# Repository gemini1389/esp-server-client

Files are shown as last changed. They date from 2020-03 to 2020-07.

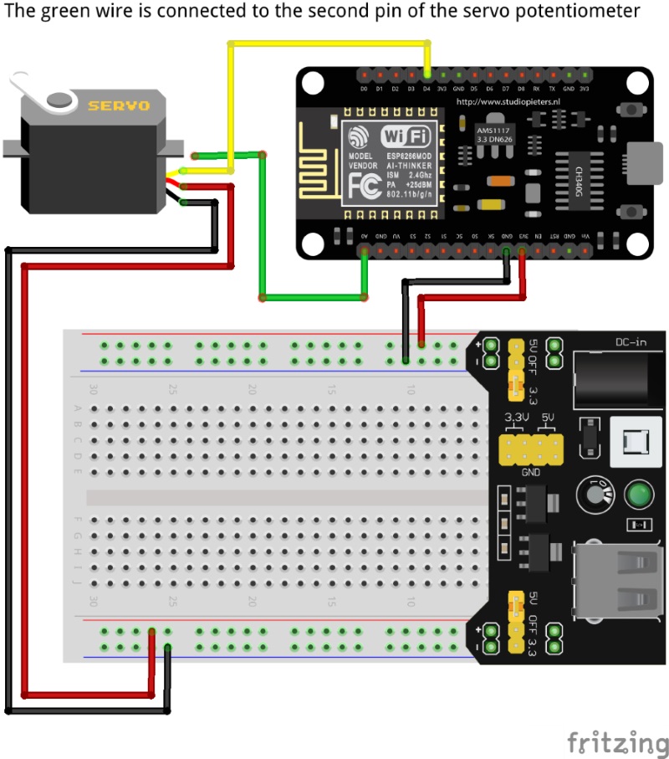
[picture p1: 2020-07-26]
main/main.jpg

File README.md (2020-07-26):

## Web Server using ESP8622 with servo and client with OLED
The project consists of two parts:
- main ([scheme](main/main.jpg))
- client ([scheme](client/client.jpg))

**main** - the web server with servo. Has a web interface for browsers that allows you to control the servo. There is also an API-like endpoint that returns the servo status in JSON format.

**client** - a web client that connects to main via Wi-Fi, receives information about the status of the servo and displays it on the OLED display.

A fourth wire was connected to the servo. It is soldered
  to the second output of the potentiometer inside the servo and connected to A0 on the board. The values are not very accurate, but they are enough to understand whether the servo has turned to the desired angle or not.

This sketch is set to rotate the servo in the range of 45-105 degrees. Equivalent values were also found for analog polling of the servo.

### Interfaces

Web interface: http://192.168.1.13/

API endpoint: http://192.168.1.13/status

### Default settings
**Wi-Fi:**
```
const char* ssid     = "AGS-WiFi";
const char* password = "qwepoi123654789";
```

**Network**
```
IPAddress local_IP(192, 168, 1, 13);
IPAddress gateway(192, 168, 1, 13);
IPAddress subnet(255, 255, 255, 0);
```

**Servo**
```
#define servoDegreeMin  45  // 0
#define servoDegreeMax  105 // 170

#define servoAnalogMin  348 // 221
#define servoAnalogMax  493 // 665
```

### Libraries for Arduino IDE:
- [ESP8266 and ESP32 OLED driver for SSD1306 displays](https://github.com/ThingPulse/esp8266-oled-ssd1306)
- [Arduino_JSON](http://github.com/arduino-libraries/Arduino_JSON)
- [Servo](http://www.arduino.cc/en/Reference/Servo)

### Hardware for project:
- Lolin NodeMCU v3 (x2)
- Sparkfun S05NF (micro)
- 0.96" OLED Display Module 128X64 I2C
- Dupont wires
- Breadboard
- Micro USB Cable
- MB102 Breadboard Power Supply
- DC 9V 1A Power Supply Adapter 5.5x2.1mm

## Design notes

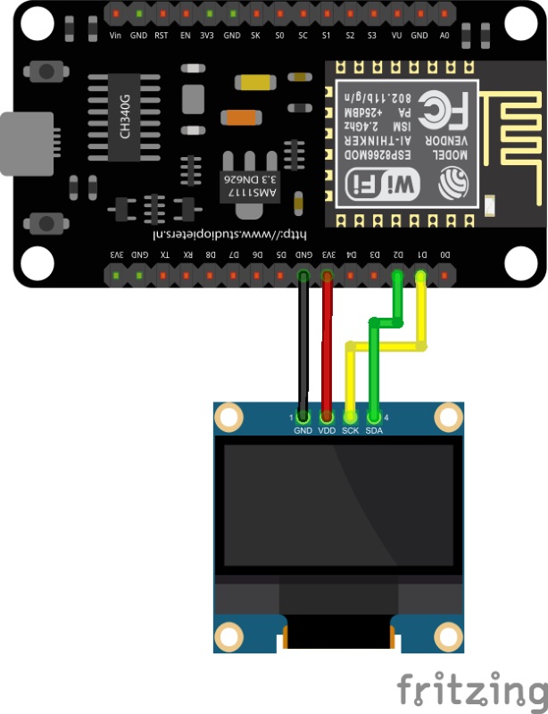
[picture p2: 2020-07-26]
client/client.jpg

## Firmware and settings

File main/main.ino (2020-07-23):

#include <Servo.h>
#include <ESP8266WiFi.h>
#include <ESP8266WebServer.h>
#include <Arduino_JSON.h>

// Print messages to Serial
#define DEBUG_MODE true

// GPIO the servo is attached to
#define pinServo        D4
#define pinServoAnalog  A0

// Config for servo
#define servoDelay        8
#define servoDiagDelay    30
#define servoMinUs        720  // 0
#define servoMaxUs        2400 // 180
#define servoMaxAttempts  3

// Min and max degree for rotation servo
#define servoDegreeMin  45  // 0
#define servoDegreeMax  105 // 170

// Min and max analog values
#define servoAnalogMin  348 // 221
#define servoAnalogMax  493 // 665

// Possible difference between values
#define servoAnalogDegreesDiff  5
#define servoAnalogAnalogDiff   50

// Credentials for Wi-Fi
const char* ssid     = "AGS-WiFi";
const char* password = "qwepoi123654789";

// Config for network
IPAddress local_IP(192, 168, 1, 13);
IPAddress gateway(192, 168, 1, 13);
IPAddress subnet(255, 255, 255, 0);

int newDegree = servoDegreeMin;
int analogDegree;
unsigned long timer;

Servo servo;
ESP8266WebServer server(80);

void setup() {
  delay(2000);

  if (DEBUG_MODE) {
    Serial.begin(115200);
  }
  println("[INIT] Debug mode is enabled");
  println("[INIT] Starting...");

  initWiFi();
  println("--------------");
  initServer();
  println("--------------");
  initServo();
  println("--------------");
  servoDiagnostics();

  println("[INIT] Initialization is complete");
}

void loop() {
  server.handleClient();
}

// Rotate servo
bool writeServo(int degree, bool isDiagnostics = false) {
  int start = getAnalogDegree();
  int end = degree;
  int position;

  if (start > end) {
    for (position = start; position >= end; position--)
    {
      servo.write(position);
      delay(isDiagnostics ? servoDiagDelay : servoDelay);
    }
  } else {
    for (position = start; position <= end; position++)
    {
      servo.write(position);
      delay(isDiagnostics ? servoDiagDelay : servoDelay);
    }
  }

  delay(100);

  return isServoRotated(degree);
}

// Main page
void handleRoot() {
  String ptr = "<!DOCTYPE html> <html>\n";
  ptr += "<head>\n";
  ptr += "<meta name=\"viewport\" content=\"width=device-width, initial-scale=1\">\n";
  ptr += "<link rel=\"icon\" href=\"data:,\">\n";

  ptr += "<style>body { text-align: center; font-family: \"Trebuchet MS\", Arial; margin-left:auto; margin-right:auto;}\n";
  ptr += ".slider { width: 300px; }</style>\n";

  // Web Page
  ptr += "</head><body><h1>ESP8266 with Servo</h1>\n";
  ptr += "<p>Position: <span id=\"servoPos\"></span></p>\n";
  ptr += "<input type=\"range\" min=\"" + String(servoDegreeMin) + "\" max=\"" + String(servoDegreeMax) + "\" class=\"slider\" id=\"servoSlider\" value=\"" + String(newDegree) + "\"/>";

  ptr += "<script>\n";
  ptr += "  var slider = document.getElementById(\"servoSlider\");\n";
  ptr += "  var servoP = document.getElementById(\"servoPos\");\n";
  ptr += "  servoP.innerHTML = slider.value;\n";
  ptr += "  slider.oninput = function() {\n";
  ptr += "    slider.value = this.value;\n";
  ptr += "    servoP.innerHTML = this.value;\n";
  ptr += "  }\n";
  ptr += "function servo() {\n";
  ptr += "  var xmlHttp = new XMLHttpRequest();\n";
  ptr += "  xmlHttp.open('GET', '/?value=' + this.value, false);\n";
  ptr += "  xmlHttp.send(null);\n";
  ptr += "  return xmlHttp.responseText;\n";
  ptr += "}\n";
  ptr += "document.getElementById('servoSlider').addEventListener('change', servo, false);\n";
  ptr += "</script>\n";

  ptr += "</body></html>";

  //GET /?value=180 HTTP/1.1
  if (server.arg("value") != "") {
    newDegree = myConstrain(server.arg("value").toInt(), servoDegreeMin, servoDegreeMax);

    bool rotated = false;
    byte attempts = 1;
    while (!rotated && attempts <= servoMaxAttempts) {
      rotated = writeServo(newDegree);
      if (!rotated) {
        println("[FAIL] Servo rotation error! Attempt: " + String(attempts) + "/" + String(servoMaxAttempts));
        attempts++;
        delay(100);
      }
    }
  }

  server.send(200, "text/html", ptr);
}

// Endpoint for getting status
void handleStatus() {
  JSONVar statusObj;

  statusObj["servoDegreeCurrent"] = newDegree;
  statusObj["servoDegreeMin"] = servoDegreeMin;
  statusObj["servoDegreeMax"] = servoDegreeMax;

  server.send(200, "application/json", JSON.stringify(statusObj));
}

// My constrain function
int myConstrain(int value, int minVal, int maxVal) {
  if (value < minVal) {
    value = minVal;
  }

  if (value > maxVal) {
    value = maxVal;
  }
  return value;
}

// Returns analog degree for servo
int getAnalogDegree() {
  int analogVal = analogRead(pinServoAnalog);
  analogVal = myConstrain(analogVal, servoAnalogMin, servoAnalogMax);
  analogDegree = map(analogVal, servoAnalogMin, servoAnalogMax, servoDegreeMin, servoDegreeMax);

  return analogDegree;
}

// It returns the status of whether the servo turned
bool isServoRotated(int degreeNeedle) {
  bool rotated = false;

  // Check by analog value
  int analogVal = analogRead(pinServoAnalog);
  int checkMinAnalog = servoAnalogMin - servoAnalogAnalogDiff;
  int checkMaxAnalog = servoAnalogMax + servoAnalogAnalogDiff;
  rotated = analogVal > checkMinAnalog && analogVal < checkMaxAnalog;

  print("[INFO] Analog: ");
  print(String(analogVal));
  println(" | Diff min: " + String(checkMinAnalog) + " | Diff max: " + String(checkMaxAnalog));

  // Check by digital value
  if (rotated) {
    int degreeAnalog = getAnalogDegree();
    int checkMin = degreeNeedle - servoAnalogDegreesDiff;
    int checkMax = degreeNeedle + servoAnalogDegreesDiff;
    rotated = degreeAnalog > checkMin && degreeAnalog < checkMax;

    print("[INFO] Digital: ");
    print(String(degreeAnalog) + "/" + String(degreeNeedle) + " (Analog/Digital)");
    println(" | Diff min: " + String(checkMin) + " | Diff max: " + String(checkMax));
  }

  println(rotated ? "[OK] Servo is rotated!" : "[FAIL] Servo is not rotated!");

  return rotated;
}

// Wi-Fi initialization
void initWiFi() {
  WiFi.softAPConfig(local_IP, gateway, subnet);
  while (WiFi.softAP(ssid, password) != true) {
    delay(750);
  }

  println("[INIT] AP SSID: " + String(ssid));
  println("[INIT] AP IP: " + WiFi.softAPIP().toString());
}

// Servo initialization
void initServo() {
  pinMode(pinServoAnalog, INPUT);

  servo.attach(
    pinServo,
    servoMinUs,
    servoMaxUs
  );

  if (servo.attached()) {
    println("[INIT] Servo attached");
  }

  writeServo(newDegree);
}

// Server initialization
void initServer() {
  server.on("/", handleRoot);
  server.on("/status", handleStatus);
  server.begin();

  println("[INIT] HTTP server started");
}

// Diagnostics for servo
void servoDiagnostics() {
  println("[INIT] Servo diagnostics: start");

  bool diagStatus = true;
  diagStatus = writeServo(servoDegreeMax, true);

  print(diagStatus ? "[OK]" : "[FAIL]");
  println(" Servo diagnostics #1 (to " + String(servoDegreeMax) + "°)");

  if (diagStatus) {
    diagStatus = writeServo(servoDegreeMin, true);
  }

  print(diagStatus ? "[OK]" : "[FAIL]");
  println(" Servo diagnostics #2 (to " + String(servoDegreeMin) + "°)");

  if (diagStatus) {
    diagStatus = writeServo(servoDegreeMax, true);
  }

  print(diagStatus ? "[OK]" : "[FAIL]");
  println(" Servo diagnostics #3 (to " + String(servoDegreeMax) + "°)");

  if (diagStatus) {
    diagStatus = writeServo(servoDegreeMin, true);
  }

  print(diagStatus ? "[OK]" : "[FAIL]");
  println(" Servo diagnostics #4 (to " + String(servoDegreeMin) + "°)");

  if (!diagStatus) {
    while (true) {
      if (millis() - timer >= 3000) {
        timer = millis();
        println("[FAIL] Servo diagnostics: Shit happens...");
      }
    }
  }

  println("[INIT] Servo diagnostics: success");
}

// Print message to Serial
void print(String message) {
  if (DEBUG_MODE) {
    Serial.print(message);
  }
}

// Print message to Serial
void println(String message) {
  if (DEBUG_MODE) {
    Serial.println(message);
  }
}

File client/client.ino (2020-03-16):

#include <ESP8266WiFi.h>
#include <ESP8266HTTPClient.h>
#include <WiFiClient.h>
#include <SSD1306Wire.h>
#include <Arduino_JSON.h>

// Print messages to Serial
#define DEBUG_MODE true

// GPIO the display is attached to
#define pinDisplaySDA D2
#define pinDisplaySCL D1

// Credentials for Wi-Fi
const char* ssid     = "AGS-WiFi";
const char* password = "qwepoi123654789";

// Endpoints
const char* endpointStatus = "http://192.168.1.13/status";

const long interval = 2 * 1000;
unsigned long previousMillis = 0;
bool doReconnect = false;

int servoDegreeCurrent;
int servoDegreeMin;
int servoDegreeMax;
int progress;

SSD1306Wire display(0x3c, pinDisplaySDA, pinDisplaySCL);

void setup() {
  delay(2000);

  if (DEBUG_MODE) {
    Serial.begin(74880);
  }
  println("Debug mode is enabled");
  println("Starting...");

  initDisplay();
  initWiFi();
}

void loop() {
  unsigned long currentMillis = millis();

  if (currentMillis - previousMillis >= interval) {
    if (WiFi.isConnected()) {
      processing();

      // save the last HTTP GET Request
      previousMillis = currentMillis;
    }
    else {
      doReconnect = true;
      println("WiFi Disconnected");
    }

    if (doReconnect) {
        WiFi.reconnect();
        connectionWiFi();
        doReconnect = false;
        println("WiFi Reconnected");
    }
  }
}

// Processing
void processing() {
  JSONVar payload = httpGETRequest(endpointStatus);

  if (payload.hasOwnProperty("servoDegreeCurrent")
      && payload.hasOwnProperty("servoDegreeMin")
      && payload.hasOwnProperty("servoDegreeMax"
  )) {
    servoDegreeCurrent = payload["servoDegreeCurrent"];
    servoDegreeMin = payload["servoDegreeMin"];
    servoDegreeMax = payload["servoDegreeMax"];
    progress = (servoDegreeCurrent - servoDegreeMin) * 100 / (servoDegreeMax - servoDegreeMin);

    println("Servo rotated: " + String(servoDegreeCurrent) + " | Progress: " + String(progress));
    println("Rotation min: " + String(servoDegreeMin) + " | Rotation max: " + String(servoDegreeMax));

    getDisplayHeader();
    display.setFont(ArialMT_Plain_16);
    display.drawString(54, 30, String(servoDegreeCurrent) + "°");
    display.drawProgressBar(0, 46, 127, 10, progress);
    display.display();
  }
}

// Send GET request
JSONVar httpGETRequest(const char* endpoint) {
  WiFiClient client;
  HTTPClient http;

  String data = "";
  if (http.begin(client, endpoint)) {
    int httpResponseCode = http.GET();
    println("Response code: " + String(httpResponseCode));

    if (httpResponseCode > 0) {
      data = http.getString();
    } else {
      doReconnect = true;
      println("Bad request");
    }
  }
  else {
    doReconnect = true;
    println("Unable to connect");
  }

  // Free resources
  http.end();

  JSONVar payload = JSON.parse(data);

  return payload;
}

// Get header for display
void getDisplayHeader() {
  display.setFont(ArialMT_Plain_10);
  display.clear();
  display.drawString(0, 0, "AP SSID: " + String(ssid));
  display.drawString(0, 13, "Client IP: " + WiFi.localIP().toString());
}

// Get connection status as string
void getConnectionStatus(int status) {
  String statusString = "Unknown";

  switch (status)
  {
    case WL_NO_SHIELD:        // 255
      statusString = "WL_NO_SHIELD";
      break;
    case WL_IDLE_STATUS:      // 0
      statusString = "WL_IDLE_STATUS";
      break;
    case WL_NO_SSID_AVAIL:    // 1
      statusString = "WL_NO_SSID_AVAIL";
      break;
    case WL_SCAN_COMPLETED:   // 2
      statusString = "WL_SCAN_COMPLETED";
      break;
    case WL_CONNECTED:        // 3
      statusString = "WL_CONNECTED";
      break;
    case WL_CONNECT_FAILED:   // 4
      statusString = "WL_CONNECT_FAILED";
      break;
    case WL_CONNECTION_LOST:  // 5
      statusString = "WL_CONNECTION_LOST";
      break;
    case WL_DISCONNECTED:     // 6
      statusString = "WL_DISCONNECTED";
      break;
  }

  display.clear();
  display.setFont(ArialMT_Plain_10);
  display.drawString(0, 0, "Connecting to " + String(ssid));
  display.drawString(0, 13, statusString);
  display.display();

  println("Connecting to " + String(ssid) + "... " + statusString);
}

// Connect to Wi-Fi
void connectionWiFi() {
  getConnectionStatus(WiFi.status());
  while (!WiFi.isConnected()) {
    delay(750);
    getConnectionStatus(WiFi.status());
  }
}

// Wi-Fi initialization
void initWiFi() {
  // Connect to Wi-Fi network with SSID and password
  WiFi.mode(WIFI_STA);
  WiFi.setAutoConnect(true);
  WiFi.setAutoReconnect(true);
  WiFi.begin(ssid, password);

  connectionWiFi();

  getDisplayHeader();
  display.display();

  // Print local IP address and start web server
  println("");
  println("WiFi connected.");
  println("Client IP: " + WiFi.localIP().toString());
}

// Display initialization
void initDisplay() {
  display.init();
  display.clear();
  display.flipScreenVertically();

  println("Display initialized");
}

// Print message to Serial
void println(String message) {
  if (DEBUG_MODE) {
    Serial.println(message);
  }
}

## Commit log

2020-03-15 Added sketch for the main device
2020-03-15 Added sketch for the client device
2020-03-16 Speed and analog pin for servo
2020-07-19 Analog pin for servo and optimizations
2020-07-23 Additional logs and diagnostics for servo
2020-07-26 Schemes and Fritzing files
    [client.fzz, main.fzz]
